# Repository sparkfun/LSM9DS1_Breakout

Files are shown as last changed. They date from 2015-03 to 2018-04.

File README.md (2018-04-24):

SparkFun LSM9DS1 Breakout
========================================

LSM9DS1 Breakout

[*LSM9DS1 Breakout (SEN-13284)*](https://www.sparkfun.com/products/13284)

The LSM9DS1 is a versatile, motion-sensing system-in-a-chip. It houses a 3-axis accelerometer, 3-axis gyroscope, and 3-axis magnetometer – nine degrees of freedom (9DOF) in a single IC! The LSM9DS1 is equipped with a digital interface, but even that is flexible: it supports both I2C and SPI, so you’ll be hard-pressed to find a microcontroller it doesn’t work with. This IMU-in-a-chip is so cool we put it on the quarter-sized breakout board you are currently viewing!

Repository Contents
-------------------

* **/Documentation** - Data sheets, additional product information
* **/Hardware** - Eagle design files (.brd, .sch)
* **/Libraries** - Libraries for use with the LSM9DS1 Breakout
* **/Production** - Production panel files (.brd)

Documentation
--------------
* **[Library](https://github.com/sparkfun/SparkFun_LSM9DS1_Arduino_Library)** - Arduino library for the LSM9DS1 Breakout.
* **[Hookup Guide](https://learn.sparkfun.com/tutorials/lsm9ds1-breakout-hookup-guide)** - Basic hookup guide for the LSM9DS1 Breakout.
* **[SparkFun Fritzing repo](https://github.com/sparkfun/Fritzing_Parts)** - Fritzing diagrams for SparkFun products. This part can be found in the products folder.

Product Versions
----------------
* [SEN-13284](https://www.sparkfun.com/products/13284)- LSM9DS1 Breakout board

Version History
---------------
* [V_1.0.0](https://github.com/sparkfun/LSM9DS1_Breakout/releases/tag/V_1.0.0) - Initial product release repository

License Information
-------------------

This product is _**open source**_! 

Please review the LICENSE.md file for license information. 

If you have any questions or concerns on licensing, please contact techsupport@sparkfun.com.

Distributed as-is; no warranty is given.

- Your friends at SparkFun.

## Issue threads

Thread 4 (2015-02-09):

Text smaller than 0.032"

ericorosel, 2015-02-09:
Not sure what GP will do, but the "2" in the "I2C" label for SJ3 is 0.025" size font

ToniCorinne, 2016-03-07:
This has been fixed. Closing this issue out.

Closed 2016-03-07.

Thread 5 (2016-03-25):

'printAttitude' was not declared in this scope

olafurjt13, 2016-03-25:
I'm trying to use the SPI example to get data from the LSM9DS1 breakout board but I can't find the printAttitude function anywhere. I've looked into the source files and can't seem to find it. Am I doing something wrong?

balamsoto, 2016-03-30:
Have same problem

bboyho, 2018-04-24:
Hi,

I was looking through the issues and noticed that you had an issue compiling. I'm not sure what Arduino IDE version you are using. However, there should be a `printAttitude()` function defined in the **LSM9DS1_Basic_SPI.ino** [ [https://github.com/sparkfun/LSM9DS1_Breakout/blob/master/Libraries/Arduino/examples/LSM9DS1_Basic_SPI/LSM9DS1_Basic_SPI.ino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](https://github.com/sparkfun/LSM9DS1_Breakout/blob/master/Libraries/Arduino/examples/LSM9DS1_Basic_SPI/LSM9DS1_Basic_SPI.ino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) ] example. Testing out with Arduino IDE v1.8.3 using the library in this repository, I had no issues compiling. I also tried testing it with the GitHub repository for the [SparkFun_LSM9DS1_Arduino_Library](https://github.com/sparkfun/SparkFun_LSM9DS1_Arduino_Library) and there were no issues.

Try using a different Arduino IDE version or reinstalling the library. Certain versions of the Arduino IDE compile differently and it may be expecting the modular functions before the `void setup(){}` and `void loop(){}` functions.

bboyho, 2018-04-24:
I just downloaded Arduino IDE v1.6.8 and confirmed that this issue was due to the Arduino IDE version. I recommend that you use a different IDE version to compile like v1.8.5.

Closed 2018-04-24.

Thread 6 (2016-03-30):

'printAttitude' was not declared in this scope

balamsoto, 2016-03-30:
Arduino 1.6.8
Mac Os el Capitan

bboyho, 2018-04-24:
It looks like you have the same issue as this case => https://github.com/sparkfun/LSM9DS1_Breakout/issues/5 . Here is my response from the other thread that may be of some use:

---

Hi,

I was looking through the issues and noticed that you had an issue compiling. I'm not sure what Arduino IDE version you are using. However, there should be a `printAttitude()` function defined in the **LSM9DS1_Basic_SPI.ino** [ [https://github.com/sparkfun/LSM9DS1_Breakout/blob/master/Libraries/Arduino/examples/LSM9DS1_Basic_SPI/LSM9DS1_Basic_SPI.ino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](https://github.com/sparkfun/LSM9DS1_Breakout/blob/master/Libraries/Arduino/examples/LSM9DS1_Basic_SPI/LSM9DS1_Basic_SPI.ino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) ] example. Testing out with Arduino IDE v1.8.3 using the library in this repository, I had no issues compiling. I also tried testing it with the GitHub repository for the [SparkFun_LSM9DS1_Arduino_Library](https://github.com/sparkfun/SparkFun_LSM9DS1_Arduino_Library) and there were no issues.

Try using a different Arduino IDE version or reinstalling the library. Certain versions of the Arduino IDE compile differently and it may be expecting the modular functions before the `void setup(){}` and `void loop(){}` functions.

bboyho, 2018-04-24:
I just downloaded Arduino IDE v1.6.8 and confirmed that this issue was due to the Arduino IDE version. I recommend that you use a different IDE version to compile like v1.8.5.

Closed 2018-04-24.

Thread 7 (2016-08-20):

No need to wait for data after Wire.requestFrom()

Koepel, 2016-08-20:
In two places in SparkFunLSM9DS1.cpp, there is a while-loop with a delay after the Wire.requestFrom() call. That while-loop is not needed and that delay is not needed.

When the Wire.requestFrom() function returns, the I2C transaction has completely finished and the received data is in the receive buffer in the Wire library. The Wire.read() only reads data from that buffer.

Grahldg, 2018-08-24:
Thanks for pointing this out, they've been removed in the latest commit.

Closed 2018-08-24.

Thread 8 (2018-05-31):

Heading is incorrect

runchangkang, 2018-05-31:
Hello I tried to implement your example basic I2C sample.
The pitch and roll are working fine.
However. the heading data is not changing correctly while rotating the board.
I tried to call calibrateMag() in setup, but the result is still incorrect
Is there any hint I can fix it? Thank you very much

Grahldg, 2018-08-27:
On further inspection I found that the way the heading was calculated was producing a range greater than 360 degrees.  I have updated the calculation and tested that it does produce values ranging from -180 degrees to 180 degrees.  All examples reflect this in the latest commit.  If you have any questions or are still experiencing any issues, please let me know.

Closed 2018-09-28.

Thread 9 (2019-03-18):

Usage of Wire library

Koepel, 2019-03-18:
The fix for [No need to wait for data after Wire.requestFrom()](https://github.com/sparkfun/LSM9DS1_Breakout/issues/7) was not fully successful.

In the file "https://github.com/sparkfun/LSM9DS1_Breakout/blob/master/Libraries/Arduino/src/SparkFunLSM9DS1.cpp"  there are two leftovers with the variable `timeout` in the functions I2CreadByte() and I2CreadBytes().
Those functions also use `Wire.endTransmission(true);` with the comment that a repeated start will be used. That is the other way around, because that parameter should be `false` for a repeated start.

The `timeout` variable can be removed. If you want, you can add a check if data was read from the sensor.

For example:
```
Wire.requestFrom(address, (uint8_t) 1);  // Read one byte from slave register address
if(Wire.available() != 1)
  return 255; //! Bad! 255 will be misinterpreted as a good value.

```
and:
```
Wire.requestFrom(address, count);  // Read bytes from slave register address
if(Wire.available() != count)
  return -1;

```

edspark, 2023-11-01:
Looks like this was silently fixed at some point years ago: https://github.com/sparkfun/LSM9DS1_Breakout/commit/ed83945ff5228455028c26a990edbc3c8d113508

Closed 2023-11-01.

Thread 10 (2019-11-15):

Example Code for I2C not working on SAMD21 Mini Breakout

savejeff, 2019-11-15:
Hi,

I had issues with the I2C Basic Example that were easily fixed:

The first try to init the imu with the line "if(!imu.begin()) fails on the first try and causes it to stuck in "while 1;"

The fix is ether to create a "while(!imu.begin()){ [print error msg and wait 1s] }"
or just wait for example 100ms before trying to connect.
This is the code fix I am proposing:

`

// The above lines will only take effect AFTER calling
  // imu.begin(), which verifies communication with the IMU
  // and turns it on.
  delay(100);
  while(!imu.begin())
  {
    Serial.println("Failed to communicate with LSM9DS1.");
    Serial.println("Double-check wiring.");
    Serial.println("Default settings in this sketch will " \
                  "work for an out of the box LSM9DS1 " \
                  "Breakout, but may need to be modified " \
                  "if the board jumpers are.");
                delay(1000);
  }

`

I also recommend adding a wait for Serial to connect to see the first error msg:

`
SerialUSB.begin(115200);
  while (!SerialUSB);
`

savan8192, 2020-01-16:
Hi Jeff, this is unlikely to make much difference!

savejeff, 2020-01-16:
It **did** make the difference

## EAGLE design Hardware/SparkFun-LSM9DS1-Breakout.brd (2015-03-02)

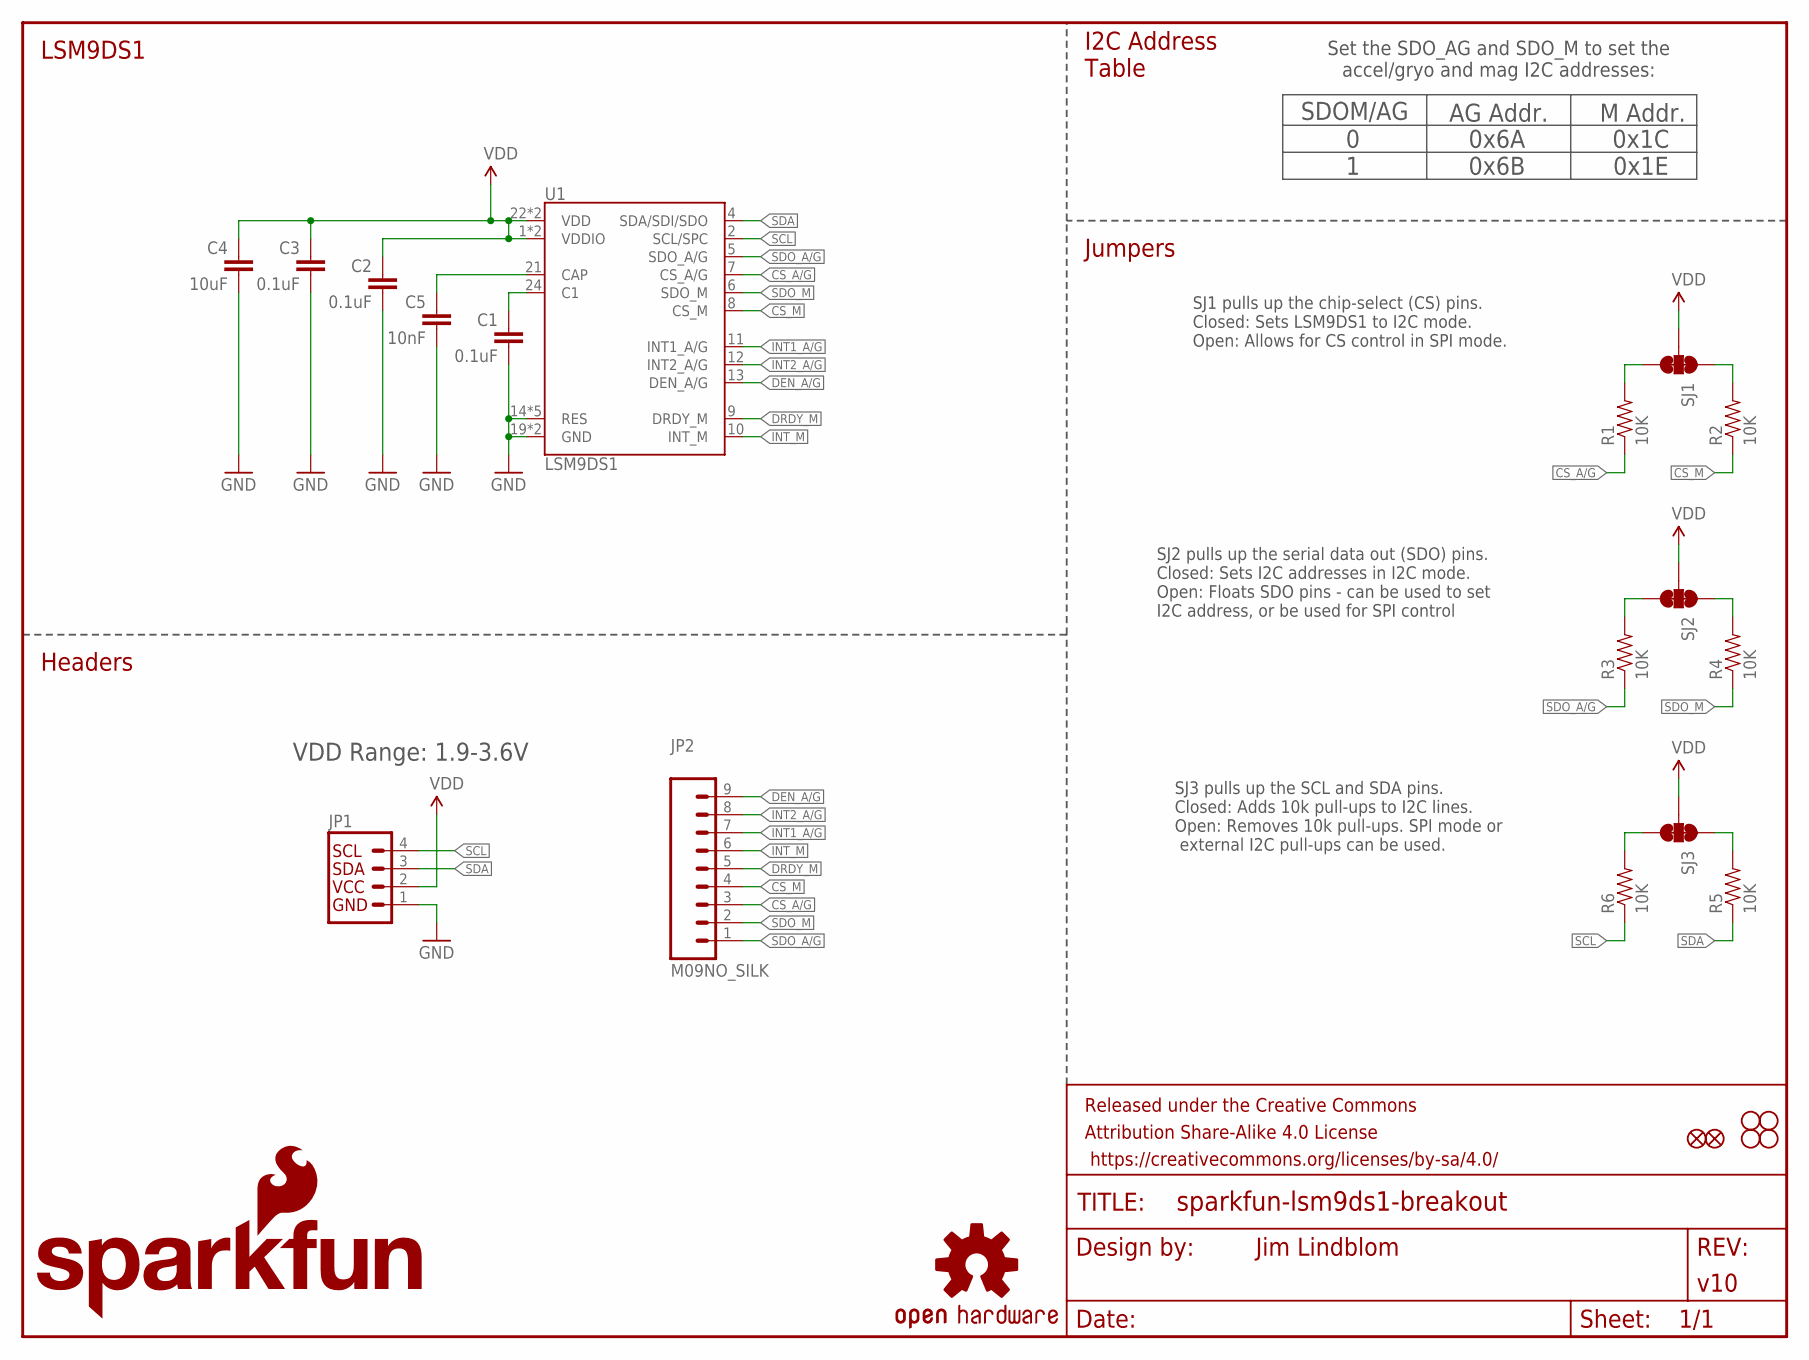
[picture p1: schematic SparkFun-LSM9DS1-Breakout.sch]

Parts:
C1, C2, C3: 0.1uF; 0603-CAP
C4: 10uF; 0603-CAP
C5: 10nF; 0603-CAP
FID1, FID2: FIDUCIAL1X2; FIDUCIAL-1X2
FRAME1: FRAME-LETTER; CREATIVE_COMMONS
JP1: I2C_STANDARD_NO_SILK; 1X04_NO_SILK
JP2: M09NO_SILK; 1X09_NO_SILK
LOGO1: SFE_LOGO_NAME.1_INCH; SFE_LOGO_NAME_.1
LOGO2: SFE_LOGO_FLAME.2_INCH; SFE_LOGO_FLAME_.2
LOGO3: OSHW-LOGOS; OSHW-LOGO-S
R1, R2, R3, R4, R5, R6: 10K; 0603-RES
SJ1, SJ2, SJ3: JUMPER-PAD-3-NC_BY_TRACE; PAD-JUMPER-3-3OF3_NC_BY_TRACE_YES_SILK_FULL_BOX
STANDOFF1, STANDOFF2, STANDOFF3, STANDOFF4: STAND-OFF
U1: LSM9DS1; LGA24-8X4

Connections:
C1: C1.1, U1.24 (C1)
CAP: C5.1, U1.21 (CAP)
CS_A/G: JP2.3, R1.1, U1.7 (CS_A/G)
CS_A/G_PU: R1.2, SJ1.3
CS_M: JP2.4, R2.1, U1.8 (CS_M)
CS_M_PU: R2.2, SJ1.1
DEN_A/G: JP2.9, U1.13 (DEN_A/G)
DRDY_M: JP2.5, U1.9 (DRDY_M)
GND: C1.2, C2.2, C3.2, C4.2, C5.2, JP1.1, U1.14 (RES), U1.15 (RES), U1.16 (RES), U1.17 (RES), U1.18 (RES), U1.19 (GND), U1.20 (GND)
INT1_A/G: JP2.7, U1.11 (INT1_A/G)
INT2_A/G: JP2.8, U1.12 (INT2_A/G)
INT_M: JP2.6, U1.10 (INT_M)
SCL: JP1.4, R6.1, U1.2 (SCL/SPC)
SCL_PU: R6.2, SJ3.3
SDA: JP1.3, R5.1, U1.4 (SDA/SDI/SDO)
SDA_PU: R5.2, SJ3.1
SDO_A/G: JP2.1, R3.1, U1.5 (SDO_A/G)
SDO_A/G_PU: R3.2, SJ2.3
SDO_M: JP2.2, R4.1, U1.6 (SDO_M)
SDO_M_PU: R4.2, SJ2.1
VDD: C2.1, C3.1, C4.1, JP1.2, SJ1.2, SJ2.2, SJ3.2, U1.1 (VDDIO), U1.3 (VDDIO), U1.22 (VDD), U1.23 (VDD)

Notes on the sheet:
SDOM/AG
0x1C 0x1E
AG Addr.
0 1
M Addr.
0x6A 0x6B
Set the SDO_AG and SDO_M to set the accel/gryo and mag I2C addresses:
SJ1 pulls up the chip-select (CS) pins. Closed: Sets LSM9DS1 to I2C mode. Open: Allows for CS control in SPI mode.
SJ2 pulls up the serial data out (SDO) pins. Closed: Sets I2C addresses in I2C mode. Open: Floats SDO pins - can be used to set I2C address, or be used for SPI control
SJ3 pulls up the SCL and SDA pins. Closed: Adds 10k pull-ups to I2C lines. Open: Removes 10k pull-ups. SPI mode or external I2C pull-ups can be used.
Jumpers
I2C Address Table
LSM9DS1
Headers
VDD Range: 1.9-3.6V

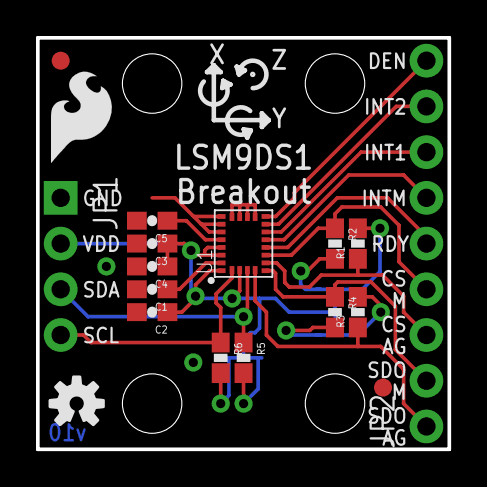
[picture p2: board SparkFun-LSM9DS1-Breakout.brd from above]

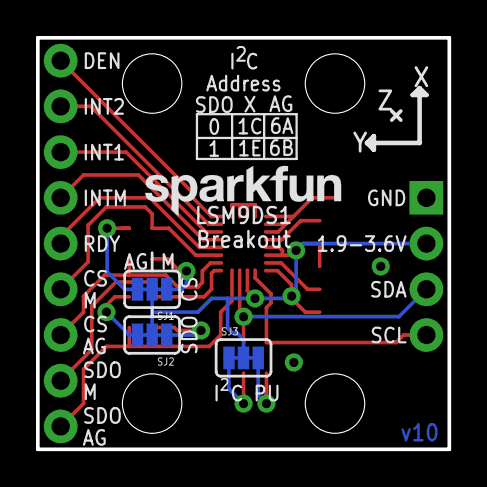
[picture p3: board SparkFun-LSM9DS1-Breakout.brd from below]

Board: 2 copper layers, 22.9 x 22.9 mm, 27 parts (4 on the bottom side), 21 nets.

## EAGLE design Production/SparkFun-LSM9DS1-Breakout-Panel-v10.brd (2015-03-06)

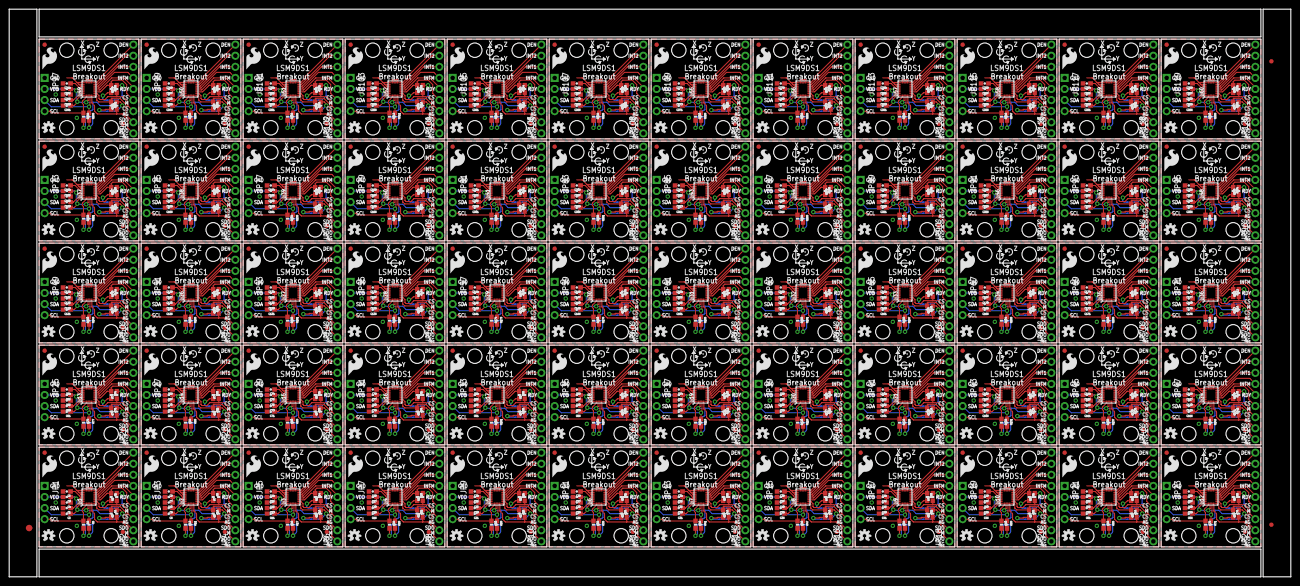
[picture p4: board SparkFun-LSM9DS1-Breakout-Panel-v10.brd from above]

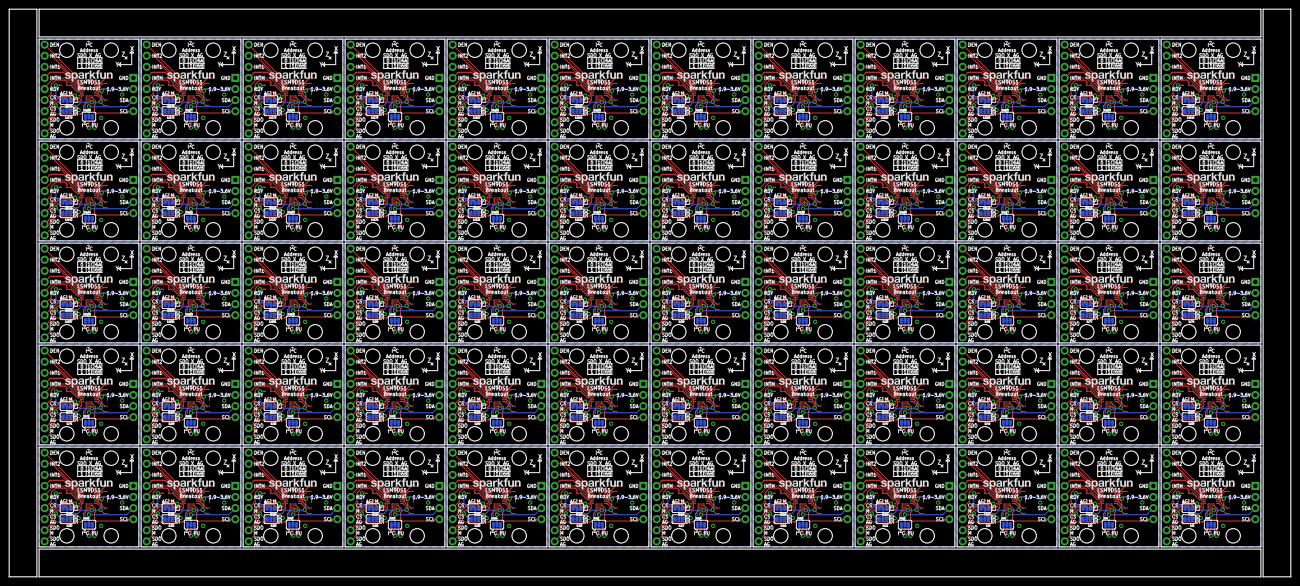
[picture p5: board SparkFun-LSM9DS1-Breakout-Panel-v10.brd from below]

Board: 2 copper layers, 293.6 x 130.0 mm, 1563 parts (240 on the bottom side), 1260 nets.

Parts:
C1, C2, C3, C6, C7, C8, C11, C12, C13, C16, C17, C18, C21, C22, C23, C26, C27, C28, C31, C32, C33, C36, C37, C38, C41, C42, C43, C46, C47, C48, C51, C52, C53, C56, C57, C58, C61, C62, C63, C66, C67, C68, C71, C72, C73, C76, C77, C78, C81, C82, C83, C86, C87, C88, C91, C92, C93, C96, C97, C98, C101, C102, C103, C106, C107, C108, C111, C112, C113, C116, C117, C118, C121, C122, C123, C126, C127, C128, C131, C132, C133, C136, C137, C138, C141, C142, C143, C146, C147, C148, C151, C152, C153, C156, C157, C158, C161, C162, C163, C166, C167, C168, C171, C172, C173, C176, C177, C178, C181, C182, C183, C186, C187, C188, C191, C192, C193, C196, C197, C198, C201, C202, C203, C206, C207, C208, C211, C212, C213, C216, C217, C218, C221, C222, C223, C226, C227, C228, C231, C232, C233, C236, C237, C238, C241, C242, C243, C246, C247, C248, C251, C252, C253, C256, C257, C258, C261, C262, C263, C266, C267, C268, C271, C272, C273, C276, C277, C278, C281, C282, C283, C286, C287, C288, C291, C292, C293, C296, C297, C298: 0.1uF; 0603-CAP
C4, C10, C15, C20, C25, C30, C35, C40, C45, C50, C55, C60, C65, C70, C75, C80, C85, C90, C95, C100, C105, C110, C115, C120, C125, C130, C135, C140, C145, C150, C155, C160, C165, C170, C175, C180, C185, C190, C195, C200, C205, C210, C215, C220, C225, C230, C235, C240, C245, C250, C255, C260, C265, C270, C275, C280, C285, C290, C295, C300: 10uF; 0603-CAP
C5, C9, C14, C19, C24, C29, C34, C39, C44, C49, C54, C59, C64, C69, C74, C79, C84, C89, C94, C99, C104, C109, C114, C119, C124, C129, C134, C139, C144, C149, C154, C159, C164, C169, C174, C179, C184, C189, C194, C199, C204, C209, C214, C219, C224, C229, C234, C239, C244, C249, C254, C259, C264, C269, C274, C279, C284, C289, C294, C299: 10nF; 0603-CAP
E$1: FIDUCIAL-1.5X3
E$4, E$5: FIDUCIAL-1X2
FID1, FID2, FID3, FID4, FID5, FID6, FID7, FID8, FID9, FID10, FID11, FID12, FID13, FID14, FID15, FID16, FID17, FID18, FID19, FID20, FID21, FID22, FID23, FID24, FID25, FID26, FID27, FID28, FID29, FID30, FID31, FID32, FID33, FID34, FID35, FID36, FID37, FID38, FID39, FID40, FID41, FID42, FID43, FID44, FID45, FID46, FID47, FID48, FID49, FID50, FID51, FID52, FID53, FID54, FID55, FID56, FID57, FID58, FID59, FID60, FID61, FID62, FID63, FID64, FID65, FID66, FID67, FID68, FID69, FID70, FID71, FID72, FID73, FID74, FID75, FID76, FID77, FID78, FID79, FID80, FID81, FID82, FID83, FID84, FID85, FID86, FID87, FID88, FID89, FID90, FID91, FID92, FID93, FID94, FID95, FID96, FID97, FID98, FID99, FID100, FID101, FID102, FID103, FID104, FID105, FID106, FID107, FID108, FID109, FID110, FID111, FID112, FID113, FID114, FID115, FID116, FID117, FID118, FID119, FID120: FIDUCIAL1X2; FIDUCIAL-1X2
JP1, JP3, JP5, JP7, JP9, JP11, JP13, JP15, JP17, JP19, JP21, JP23, JP25, JP27, JP29, JP31, JP33, JP35, JP37, JP39, JP41, JP43, JP45, JP47, JP49, JP51, JP53, JP55, JP57, JP59, JP61, JP63, JP65, JP67, JP69, JP71, JP73, JP75, JP77, JP79, JP81, JP83, JP85, JP87, JP89, JP91, JP93, JP95, JP97, JP99, JP101, JP103, JP105, JP107, JP109, JP111, JP113, JP115, JP117, JP119: 1X04_NO_SILK
JP2, JP4, JP6, JP8, JP10, JP12, JP14, JP16, JP18, JP20, JP22, JP24, JP26, JP28, JP30, JP32, JP34, JP36, JP38, JP40, JP42, JP44, JP46, JP48, JP50, JP52, JP54, JP56, JP58, JP60, JP62, JP64, JP66, JP68, JP70, JP72, JP74, JP76, JP78, JP80, JP82, JP84, JP86, JP88, JP90, JP92, JP94, JP96, JP98, JP100, JP102, JP104, JP106, JP108, JP110, JP112, JP114, JP116, JP118, JP120: M09NO_SILK; 1X09_NO_SILK
LOGO1, LOGO4, LOGO7, LOGO10, LOGO13, LOGO16, LOGO19, LOGO22, LOGO25, LOGO28, LOGO31, LOGO34, LOGO37, LOGO40, LOGO43, LOGO46, LOGO49, LOGO52, LOGO55, LOGO58, LOGO61, LOGO64, LOGO67, LOGO70, LOGO73, LOGO76, LOGO79, LOGO82, LOGO85, LOGO88, LOGO91, LOGO94, LOGO97, LOGO100, LOGO103, LOGO106, LOGO109, LOGO112, LOGO115, LOGO118, LOGO121, LOGO124, LOGO127, LOGO130, LOGO133, LOGO136, LOGO139, LOGO142, LOGO145, LOGO148, LOGO151, LOGO154, LOGO157, LOGO160, LOGO163, LOGO166, LOGO169, LOGO172, LOGO175, LOGO178: SFE_LOGO_NAME.1_INCH; SFE_LOGO_NAME_.1
LOGO2, LOGO5, LOGO8, LOGO11, LOGO14, LOGO17, LOGO20, LOGO23, LOGO26, LOGO29, LOGO32, LOGO35, LOGO38, LOGO41, LOGO44, LOGO47, LOGO50, LOGO53, LOGO56, LOGO59, LOGO62, LOGO65, LOGO68, LOGO71, LOGO74, LOGO77, LOGO80, LOGO83, LOGO86, LOGO89, LOGO92, LOGO95, LOGO98, LOGO101, LOGO104, LOGO107, LOGO110, LOGO113, LOGO116, LOGO119, LOGO122, LOGO125, LOGO128, LOGO131, LOGO134, LOGO137, LOGO140, LOGO143, LOGO146, LOGO149, LOGO152, LOGO155, LOGO158, LOGO161, LOGO164, LOGO167, LOGO170, LOGO173, LOGO176, LOGO179: SFE_LOGO_FLAME.2_INCH; SFE_LOGO_FLAME_.2
LOGO3, LOGO6, LOGO9, LOGO12, LOGO15, LOGO18, LOGO21, LOGO24, LOGO27, LOGO30, LOGO33, LOGO36, LOGO39, LOGO42, LOGO45, LOGO48, LOGO51, LOGO54, LOGO57, LOGO60, LOGO63, LOGO66, LOGO69, LOGO72, LOGO75, LOGO78, LOGO81, LOGO84, LOGO87, LOGO90, LOGO93, LOGO96, LOGO99, LOGO102, LOGO105, LOGO108, LOGO111, LOGO114, LOGO117, LOGO120, LOGO123, LOGO126, LOGO129, LOGO132, LOGO135, LOGO138, LOGO141, LOGO144, LOGO147, LOGO150, LOGO153, LOGO156, LOGO159, LOGO162, LOGO165, LOGO168, LOGO171, LOGO174, LOGO177, LOGO180: OSHW-LOGOS; OSHW-LOGO-S
R1, R2, R3, R4, R5, R6, R7, R8, R9, R10, R11, R12, R13, R14, R15, R16, R17, R18, R19, R20, R21, R22, R23, R24, R25, R26, R27, R28, R29, R30, R31, R32, R33, R34, R35, R36, R37, R38, R39, R40, R41, R42, R43, R44, R45, R46, R47, R48, R49, R50, R51, R52, R53, R54, R55, R56, R57, R58, R59, R60, R61, R62, R63, R64, R65, R66, R67, R68, R69, R70, R71, R72, R73, R74, R75, R76, R77, R78, R79, R80, R81, R82, R83, R84, R85, R86, R87, R88, R89, R90, R91, R92, R93, R94, R95, R96, R97, R98, R99, R100, R101, R102, R103, R104, R105, R106, R107, R108, R109, R110, R111, R112, R113, R114, R115, R116, R117, R118, R119, R120, R121, R122, R123, R124, R125, R126, R127, R128, R129, R130, R131, R132, R133, R134, R135, R136, R137, R138, R139, R140, R141, R142, R143, R144, R145, R146, R147, R148, R149, R150, R151, R152, R153, R154, R155, R156, R157, R158, R159, R160, R161, R162, R163, R164, R165, R166, R167, R168, R169, R170, R171, R172, R173, R174, R175, R176, R177, R178, R179, R180, R181, R182, R183, R184, R185, R186, R187, R188, R189, R190, R191, R192, R193, R194, R195, R196, R197, R198, R199, R200, R201, R202, R203, R204, R205, R206, R207, R208, R209, R210, R211, R212, R213, R214, R215, R216, R217, R218, R219, R220, R221, R222, R223, R224, R225, R226, R227, R228, R229, R230, R231, R232, R233, R234, R235, R236, R237, R238, R239, R240, R241, R242, R243, R244, R245, R246, R247, R248, R249, R250, R251, R252, R253, R254, R255, R256, R257, R258, R259, R260, R261, R262, R263, R264, R265, R266, R267, R268, R269, R270, R271, R272, R273, R274, R275, R276, R277, R278, R279, R280, R281, R282, R283, R284, R285, R286, R287, R288, R289, R290, R291, R292, R293, R294, R295, R296, R297, R298, R299, R300, R301, R302, R303, R304, R305, R306, R307, R308, R309, R310, R311, R312, R313, R314, R315, R316, R317, R318, R319, R320, R321, R322, R323, R324, R325, R326, R327, R328, R329, R330, R331, R332, R333, R334, R335, R336, R337, R338, R339, R340, R341, R342, R343, R344, R345, R346, R347, R348, R349, R350, R351, R352, R353, R354, R355, R356, R357, R358, R359, R360: 10K; 0603-RES
SJ1, SJ2, SJ3, SJ4, SJ5, SJ6, SJ7, SJ8, SJ9, SJ10, SJ11, SJ12, SJ13, SJ14, SJ15, SJ16, SJ17, SJ18, SJ19, SJ20, SJ21, SJ22, SJ23, SJ24, SJ25, SJ26, SJ27, SJ28, SJ29, SJ30, SJ31, SJ32, SJ33, SJ34, SJ35, SJ36, SJ37, SJ38, SJ39, SJ40, SJ41, SJ42, SJ43, SJ44, SJ45, SJ46, SJ47, SJ48, SJ49, SJ50, SJ51, SJ52, SJ53, SJ54, SJ55, SJ56, SJ57, SJ58, SJ59, SJ60, SJ61, SJ62, SJ63, SJ64, SJ65, SJ66, SJ67, SJ68, SJ69, SJ70, SJ71, SJ72, SJ73, SJ74, SJ75, SJ76, SJ77, SJ78, SJ79, SJ80, SJ81, SJ82, SJ83, SJ84, SJ85, SJ86, SJ87, SJ88, SJ89, SJ90, SJ91, SJ92, SJ93, SJ94, SJ95, SJ96, SJ97, SJ98, SJ99, SJ100, SJ101, SJ102, SJ103, SJ104, SJ105, SJ106, SJ107, SJ108, SJ109, SJ110, SJ111, SJ112, SJ113, SJ114, SJ115, SJ116, SJ117, SJ118, SJ119, SJ120, SJ121, SJ122, SJ123, SJ124, SJ125, SJ126, SJ127, SJ128, SJ129, SJ130, SJ131, SJ132, SJ133, SJ134, SJ135, SJ136, SJ137, SJ138, SJ139, SJ140, SJ141, SJ142, SJ143, SJ144, SJ145, SJ146, SJ147, SJ148, SJ149, SJ150, SJ151, SJ152, SJ153, SJ154, SJ155, SJ156, SJ157, SJ158, SJ159, SJ160, SJ161, SJ162, SJ163, SJ164, SJ165, SJ166, SJ167, SJ168, SJ169, SJ170, SJ171, SJ172, SJ173, SJ174, SJ175, SJ176, SJ177, SJ178, SJ179, SJ180: PAD-JUMPER-3-3OF3_NC_BY_TRACE_YES_SILK_FULL_BOX
STANDOFF1, STANDOFF2, STANDOFF3, STANDOFF4, STANDOFF5, STANDOFF6, STANDOFF7, STANDOFF8, STANDOFF9, STANDOFF10, STANDOFF11, STANDOFF12, STANDOFF13, STANDOFF14, STANDOFF15, STANDOFF16, STANDOFF17, STANDOFF18, STANDOFF19, STANDOFF20, STANDOFF21, STANDOFF22, STANDOFF23, STANDOFF24, STANDOFF25, STANDOFF26, STANDOFF27, STANDOFF28, STANDOFF29, STANDOFF30, STANDOFF31, STANDOFF32, STANDOFF33, STANDOFF34, STANDOFF35, STANDOFF36, STANDOFF37, STANDOFF38, STANDOFF39, STANDOFF40, STANDOFF41, STANDOFF42, STANDOFF43, STANDOFF44, STANDOFF45, STANDOFF46, STANDOFF47, STANDOFF48, STANDOFF49, STANDOFF50, STANDOFF51, STANDOFF52, STANDOFF53, STANDOFF54, STANDOFF55, STANDOFF56, STANDOFF57, STANDOFF58, STANDOFF59, STANDOFF60, STANDOFF61, STANDOFF62, STANDOFF63, STANDOFF64, STANDOFF65, STANDOFF66, STANDOFF67, STANDOFF68, STANDOFF69, STANDOFF70, STANDOFF71, STANDOFF72, STANDOFF73, STANDOFF74, STANDOFF75, STANDOFF76, STANDOFF77, STANDOFF78, STANDOFF79, STANDOFF80, STANDOFF81, STANDOFF82, STANDOFF83, STANDOFF84, STANDOFF85, STANDOFF86, STANDOFF87, STANDOFF88, STANDOFF89, STANDOFF90, STANDOFF91, STANDOFF92, STANDOFF93, STANDOFF94, STANDOFF95, STANDOFF96, STANDOFF97, STANDOFF98, STANDOFF99, STANDOFF100, STANDOFF101, STANDOFF102, STANDOFF103, STANDOFF104, STANDOFF105, STANDOFF106, STANDOFF107, STANDOFF108, STANDOFF109, STANDOFF110, STANDOFF111, STANDOFF112, STANDOFF113, STANDOFF114, STANDOFF115, STANDOFF116, STANDOFF117, STANDOFF118, STANDOFF119, STANDOFF120, STANDOFF121, STANDOFF122, STANDOFF123, STANDOFF124, STANDOFF125, STANDOFF126, STANDOFF127, STANDOFF128, STANDOFF129, STANDOFF130, STANDOFF131, STANDOFF132, STANDOFF133, STANDOFF134, STANDOFF135, STANDOFF136, STANDOFF137, STANDOFF138, STANDOFF139, STANDOFF140, STANDOFF141, STANDOFF142, STANDOFF143, STANDOFF144, STANDOFF145, STANDOFF146, STANDOFF147, STANDOFF148, STANDOFF149, STANDOFF150, STANDOFF151, STANDOFF152, STANDOFF153, STANDOFF154, STANDOFF155, STANDOFF156, STANDOFF157, STANDOFF158, STANDOFF159, STANDOFF160, STANDOFF161, STANDOFF162, STANDOFF163, STANDOFF164, STANDOFF165, STANDOFF166, STANDOFF167, STANDOFF168, STANDOFF169, STANDOFF170, STANDOFF171, STANDOFF172, STANDOFF173, STANDOFF174, STANDOFF175, STANDOFF176, STANDOFF177, STANDOFF178, STANDOFF179, STANDOFF180, STANDOFF181, STANDOFF182, STANDOFF183, STANDOFF184, STANDOFF185, STANDOFF186, STANDOFF187, STANDOFF188, STANDOFF189, STANDOFF190, STANDOFF191, STANDOFF192, STANDOFF193, STANDOFF194, STANDOFF195, STANDOFF196, STANDOFF197, STANDOFF198, STANDOFF199, STANDOFF200, STANDOFF201, STANDOFF202, STANDOFF203, STANDOFF204, STANDOFF205, STANDOFF206, STANDOFF207, STANDOFF208, STANDOFF209, STANDOFF210, STANDOFF211, STANDOFF212, STANDOFF213, STANDOFF214, STANDOFF215, STANDOFF216, STANDOFF217, STANDOFF218, STANDOFF219, STANDOFF220, STANDOFF221, STANDOFF222, STANDOFF223, STANDOFF224, STANDOFF225, STANDOFF226, STANDOFF227, STANDOFF228, STANDOFF229, STANDOFF230, STANDOFF231, STANDOFF232, STANDOFF233, STANDOFF234, STANDOFF235, STANDOFF236, STANDOFF237, STANDOFF238, STANDOFF239, STANDOFF240: STAND-OFF
U1, U2, U3, U4, U5, U6, U7, U8, U9, U10, U11, U12, U13, U14, U15, U16, U17, U18, U19, U20, U21, U22, U23, U24, U25, U26, U27, U28, U29, U30, U31, U32, U33, U34, U35, U36, U37, U38, U39, U40, U41, U42, U43, U44, U45, U46, U47, U48, U49, U50, U51, U52, U53, U54, U55, U56, U57, U58, U59, U60: LSM9DS1; LGA24-8X4

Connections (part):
C1: C1.1, U1.24
C2: C8.1, U2.24
C3: C13.1, U3.24
C4: C18.1, U4.24
C5: C23.1, U5.24
C6: C28.1, U6.24
C7: C33.1, U7.24
C8: C38.1, U8.24
C9: C43.1, U9.24
C10: C48.1, U10.24
C11: C53.1, U11.24
C12: C58.1, U12.24
C13: C63.1, U13.24
C14: C68.1, U14.24
C15: C73.1, U15.24
C16: C78.1, U16.24
C17: C83.1, U17.24
C18: C88.1, U18.24
C19: C93.1, U19.24
C20: C98.1, U20.24
C21: C103.1, U21.24
C22: C108.1, U22.24
C23: C113.1, U23.24
C24: C118.1, U24.24
C25: C123.1, U25.24
C26: C128.1, U26.24
C27: C133.1, U27.24
C28: C138.1, U28.24
C29: C143.1, U29.24
C30: C148.1, U30.24
C31: C153.1, U31.24
C32: C158.1, U32.24
C33: C163.1, U33.24
C34: C168.1, U34.24
C35: C173.1, U35.24
C36: C178.1, U36.24
C37: C183.1, U37.24
C38: C188.1, U38.24
C39: C193.1, U39.24
C40: C198.1, U40.24
C41: C203.1, U41.24
C42: C208.1, U42.24
C43: C213.1, U43.24
C44: C218.1, U44.24
C45: C223.1, U45.24
C46: C228.1, U46.24
C47: C233.1, U47.24
C48: C238.1, U48.24
C49: C243.1, U49.24
C50: C248.1, U50.24
C51: C253.1, U51.24
C52: C258.1, U52.24
C53: C263.1, U53.24
C54: C268.1, U54.24
C55: C273.1, U55.24
C56: C278.1, U56.24
C57: C283.1, U57.24
C58: C288.1, U58.24
C59: C293.1, U59.24
C60: C298.1, U60.24
CAP: C5.1, U1.21
CAP1: C9.1, U2.21
CAP2: C14.1, U3.21
CAP3: C19.1, U4.21
CAP4: C24.1, U5.21
CAP5: C29.1, U6.21
CAP6: C34.1, U7.21
CAP7: C39.1, U8.21
CAP8: C44.1, U9.21
CAP9: C49.1, U10.21
CAP10: C54.1, U11.21
CAP11: C59.1, U12.21
CAP12: C64.1, U13.21
CAP13: C69.1, U14.21
CAP14: C74.1, U15.21
CAP15: C79.1, U16.21
CAP16: C84.1, U17.21
CAP17: C89.1, U18.21
CAP18: C94.1, U19.21
CAP19: C99.1, U20.21
CAP20: C104.1, U21.21
CAP21: C109.1, U22.21
CAP22: C114.1, U23.21
CAP23: C119.1, U24.21
CAP24: C124.1, U25.21
CAP25: C129.1, U26.21
CAP26: C134.1, U27.21
CAP27: C139.1, U28.21
CAP28: C144.1, U29.21
CAP29: C149.1, U30.21
CAP30: C154.1, U31.21
CAP31: C159.1, U32.21
CAP32: C164.1, U33.21
CAP33: C169.1, U34.21
CAP34: C174.1, U35.21
CAP35: C179.1, U36.21
CAP36: C184.1, U37.21
CAP37: C189.1, U38.21
CAP38: C194.1, U39.21
CAP39: C199.1, U40.21
CAP40: C204.1, U41.21
CAP41: C209.1, U42.21
CAP42: C214.1, U43.21
CAP43: C219.1, U44.21
CAP44: C224.1, U45.21
CAP45: C229.1, U46.21
CAP46: C234.1, U47.21
CAP47: C239.1, U48.21
CAP48: C244.1, U49.21
CAP49: C249.1, U50.21
CAP50: C254.1, U51.21
CAP51: C259.1, U52.21
CAP52: C264.1, U53.21
CAP53: C269.1, U54.21
CAP54: C274.1, U55.21
CAP55: C279.1, U56.21
CAP56: C284.1, U57.21
CAP57: C289.1, U58.21
CAP58: C294.1, U59.21
CAP59: C299.1, U60.21
CS_A/G: JP2.3, R1.1, U1.7
CS_A/G1: JP4.3, R7.1, U2.7
CS_A/G2: JP6.3, R13.1, U3.7
CS_A/G3: JP8.3, R19.1, U4.7
CS_A/G4: JP10.3, R25.1, U5.7
CS_A/G5: JP12.3, R31.1, U6.7
CS_A/G6: JP14.3, R37.1, U7.7
CS_A/G7: JP16.3, R43.1, U8.7
CS_A/G8: JP18.3, R49.1, U9.7
CS_A/G9: JP20.3, R55.1, U10.7
CS_A/G10: JP22.3, R61.1, U11.7
CS_A/G11: JP24.3, R67.1, U12.7
CS_A/G12: JP26.3, R73.1, U13.7
CS_A/G13: JP28.3, R79.1, U14.7
CS_A/G14: JP30.3, R85.1, U15.7
CS_A/G15: JP32.3, R91.1, U16.7
CS_A/G16: JP34.3, R97.1, U17.7
CS_A/G17: JP36.3, R103.1, U18.7
CS_A/G18: JP38.3, R109.1, U19.7
CS_A/G19: JP40.3, R115.1, U20.7
CS_A/G20: JP42.3, R121.1, U21.7
CS_A/G21: JP44.3, R127.1, U22.7
CS_A/G22: JP46.3, R133.1, U23.7
CS_A/G23: JP48.3, R139.1, U24.7
CS_A/G24: JP50.3, R145.1, U25.7
CS_A/G25: JP52.3, R151.1, U26.7
CS_A/G26: JP54.3, R157.1, U27.7
CS_A/G27: JP56.3, R163.1, U28.7
CS_A/G28: JP58.3, R169.1, U29.7
CS_A/G29: JP60.3, R175.1, U30.7
CS_A/G30: JP62.3, R181.1, U31.7
CS_A/G31: JP64.3, R187.1, U32.7
CS_A/G32: JP66.3, R193.1, U33.7
CS_A/G33: JP68.3, R199.1, U34.7
CS_A/G34: JP70.3, R205.1, U35.7
CS_A/G35: JP72.3, R211.1, U36.7
CS_A/G36: JP74.3, R217.1, U37.7
CS_A/G37: JP76.3, R223.1, U38.7
CS_A/G38: JP78.3, R229.1, U39.7
CS_A/G39: JP80.3, R235.1, U40.7
CS_A/G40: JP82.3, R241.1, U41.7
CS_A/G41: JP84.3, R247.1, U42.7
CS_A/G42: JP86.3, R253.1, U43.7
CS_A/G43: JP88.3, R259.1, U44.7
CS_A/G44: JP90.3, R265.1, U45.7
CS_A/G45: JP92.3, R271.1, U46.7
CS_A/G46: JP94.3, R277.1, U47.7
CS_A/G47: JP96.3, R283.1, U48.7
CS_A/G48: JP98.3, R289.1, U49.7
CS_A/G49: JP100.3, R295.1, U50.7
CS_A/G50: JP102.3, R301.1, U51.7
CS_A/G51: JP104.3, R307.1, U52.7
CS_A/G52: JP106.3, R313.1, U53.7
CS_A/G53: JP108.3, R319.1, U54.7
CS_A/G54: JP110.3, R325.1, U55.7
CS_A/G55: JP112.3, R331.1, U56.7
CS_A/G56: JP114.3, R337.1, U57.7
CS_A/G57: JP116.3, R343.1, U58.7
CS_A/G58: JP118.3, R349.1, U59.7
CS_A/G59: JP120.3, R355.1, U60.7
CS_A/G_PU: R1.2, SJ1.3
CS_A/G_PU1: R7.2, SJ4.3
CS_A/G_PU2: R13.2, SJ7.3
CS_A/G_PU3: R19.2, SJ10.3
CS_A/G_PU4: R25.2, SJ13.3
CS_A/G_PU5: R31.2, SJ16.3
CS_A/G_PU6: R37.2, SJ19.3
CS_A/G_PU7: R43.2, SJ22.3
CS_A/G_PU8: R49.2, SJ25.3
CS_A/G_PU9: R55.2, SJ28.3
CS_A/G_PU10: R61.2, SJ31.3
CS_A/G_PU11: R67.2, SJ34.3
CS_A/G_PU12: R73.2, SJ37.3
CS_A/G_PU13: R79.2, SJ40.3
CS_A/G_PU14: R85.2, SJ43.3
CS_A/G_PU15: R91.2, SJ46.3
CS_A/G_PU16: R97.2, SJ49.3
CS_A/G_PU17: R103.2, SJ52.3
CS_A/G_PU18: R109.2, SJ55.3
CS_A/G_PU19: R115.2, SJ58.3
CS_A/G_PU20: R121.2, SJ61.3
CS_A/G_PU21: R127.2, SJ64.3
CS_A/G_PU22: R133.2, SJ67.3
CS_A/G_PU23: R139.2, SJ70.3
CS_A/G_PU24: R145.2, SJ73.3
CS_A/G_PU25: R151.2, SJ76.3
CS_A/G_PU26: R157.2, SJ79.3
CS_A/G_PU27: R163.2, SJ82.3
CS_A/G_PU28: R169.2, SJ85.3
CS_A/G_PU29: R175.2, SJ88.3
CS_A/G_PU30: R181.2, SJ91.3
CS_A/G_PU31: R187.2, SJ94.3
CS_A/G_PU32: R193.2, SJ97.3
CS_A/G_PU33: R199.2, SJ100.3
CS_A/G_PU34: R205.2, SJ103.3
CS_A/G_PU35: R211.2, SJ106.3
CS_A/G_PU36: R217.2, SJ109.3
CS_A/G_PU37: R223.2, SJ112.3
CS_A/G_PU38: R229.2, SJ115.3
CS_A/G_PU39: R235.2, SJ118.3
CS_A/G_PU40: R241.2, SJ121.3
CS_A/G_PU41: R247.2, SJ124.3
CS_A/G_PU42: R253.2, SJ127.3
CS_A/G_PU43: R259.2, SJ130.3
CS_A/G_PU44: R265.2, SJ133.3
CS_A/G_PU45: R271.2, SJ136.3
CS_A/G_PU46: R277.2, SJ139.3
CS_A/G_PU47: R283.2, SJ142.3
CS_A/G_PU48: R289.2, SJ145.3
CS_A/G_PU49: R295.2, SJ148.3
CS_A/G_PU50: R301.2, SJ151.3
CS_A/G_PU51: R307.2, SJ154.3
CS_A/G_PU52: R313.2, SJ157.3
CS_A/G_PU53: R319.2, SJ160.3
CS_A/G_PU54: R325.2, SJ163.3
CS_A/G_PU55: R331.2, SJ166.3
CS_A/G_PU56: R337.2, SJ169.3
CS_A/G_PU57: R343.2, SJ172.3
CS_A/G_PU58: R349.2, SJ175.3
CS_A/G_PU59: R355.2, SJ178.3
CS_M: JP2.4, R2.1, U1.8
CS_M1: JP4.4, R8.1, U2.8
CS_M2: JP6.4, R14.1, U3.8
CS_M3: JP8.4, R20.1, U4.8
CS_M4: JP10.4, R26.1, U5.8
CS_M5: JP12.4, R32.1, U6.8
CS_M6: JP14.4, R38.1, U7.8
CS_M7: JP16.4, R44.1, U8.8
CS_M8: JP18.4, R50.1, U9.8
CS_M9: JP20.4, R56.1, U10.8
CS_M10: JP22.4, R62.1, U11.8
CS_M11: JP24.4, R68.1, U12.8
CS_M12: JP26.4, R74.1, U13.8
CS_M13: JP28.4, R80.1, U14.8
CS_M14: JP30.4, R86.1, U15.8
CS_M15: JP32.4, R92.1, U16.8
CS_M16: JP34.4, R98.1, U17.8
CS_M17: JP36.4, R104.1, U18.8
CS_M18: JP38.4, R110.1, U19.8
CS_M19: JP40.4, R116.1, U20.8
CS_M20: JP42.4, R122.1, U21.8
CS_M21: JP44.4, R128.1, U22.8
CS_M22: JP46.4, R134.1, U23.8
CS_M23: JP48.4, R140.1, U24.8
CS_M24: JP50.4, R146.1, U25.8
CS_M25: JP52.4, R152.1, U26.8
CS_M26: JP54.4, R158.1, U27.8
CS_M27: JP56.4, R164.1, U28.8
CS_M28: JP58.4, R170.1, U29.8
CS_M29: JP60.4, R176.1, U30.8
CS_M30: JP62.4, R182.1, U31.8
CS_M31: JP64.4, R188.1, U32.8
CS_M32: JP66.4, R194.1, U33.8
CS_M33: JP68.4, R200.1, U34.8
CS_M34: JP70.4, R206.1, U35.8
CS_M35: JP72.4, R212.1, U36.8
CS_M36: JP74.4, R218.1, U37.8
CS_M37: JP76.4, R224.1, U38.8
CS_M38: JP78.4, R230.1, U39.8
CS_M39: JP80.4, R236.1, U40.8
CS_M40: JP82.4, R242.1, U41.8
CS_M41: JP84.4, R248.1, U42.8
CS_M42: JP86.4, R254.1, U43.8
CS_M43: JP88.4, R260.1, U44.8
CS_M44: JP90.4, R266.1, U45.8
CS_M45: JP92.4, R272.1, U46.8
CS_M46: JP94.4, R278.1, U47.8
CS_M47: JP96.4, R284.1, U48.8
CS_M48: JP98.4, R290.1, U49.8
CS_M49: JP100.4, R296.1, U50.8
CS_M50: JP102.4, R302.1, U51.8
CS_M51: JP104.4, R308.1, U52.8
CS_M52: JP106.4, R314.1, U53.8
CS_M53: JP108.4, R320.1, U54.8
CS_M54: JP110.4, R326.1, U55.8
CS_M55: JP112.4, R332.1, U56.8
CS_M56: JP114.4, R338.1, U57.8
CS_M57: JP116.4, R344.1, U58.8
CS_M58: JP118.4, R350.1, U59.8
CS_M59: JP120.4, R356.1, U60.8
CS_M_PU: R2.2, SJ1.1
CS_M_PU1: R8.2, SJ4.1
CS_M_PU2: R14.2, SJ7.1
CS_M_PU3: R20.2, SJ10.1
CS_M_PU4: R26.2, SJ13.1
CS_M_PU5: R32.2, SJ16.1
CS_M_PU6: R38.2, SJ19.1
CS_M_PU7: R44.2, SJ22.1
CS_M_PU8: R50.2, SJ25.1
CS_M_PU9: R56.2, SJ28.1
CS_M_PU10: R62.2, SJ31.1
CS_M_PU11: R68.2, SJ34.1
CS_M_PU12: R74.2, SJ37.1
CS_M_PU13: R80.2, SJ40.1
CS_M_PU14: R86.2, SJ43.1
CS_M_PU15: R92.2, SJ46.1
CS_M_PU16: R98.2, SJ49.1
CS_M_PU17: R104.2, SJ52.1
CS_M_PU18: R110.2, SJ55.1
CS_M_PU19: R116.2, SJ58.1
CS_M_PU20: R122.2, SJ61.1
CS_M_PU21: R128.2, SJ64.1
CS_M_PU22: R134.2, SJ67.1
CS_M_PU23: R140.2, SJ70.1
CS_M_PU24: R146.2, SJ73.1
CS_M_PU25: R152.2, SJ76.1
CS_M_PU26: R158.2, SJ79.1
CS_M_PU27: R164.2, SJ82.1
CS_M_PU28: R170.2, SJ85.1
CS_M_PU29: R176.2, SJ88.1
CS_M_PU30: R182.2, SJ91.1
CS_M_PU31: R188.2, SJ94.1
CS_M_PU32: R194.2, SJ97.1
CS_M_PU33: R200.2, SJ100.1
CS_M_PU34: R206.2, SJ103.1
CS_M_PU35: R212.2, SJ106.1
CS_M_PU36: R218.2, SJ109.1
CS_M_PU37: R224.2, SJ112.1
CS_M_PU38: R230.2, SJ115.1
CS_M_PU39: R236.2, SJ118.1
CS_M_PU40: R242.2, SJ121.1
CS_M_PU41: R248.2, SJ124.1
CS_M_PU42: R254.2, SJ127.1
CS_M_PU43: R260.2, SJ130.1
CS_M_PU44: R266.2, SJ133.1
CS_M_PU45: R272.2, SJ136.1
CS_M_PU46: R278.2, SJ139.1
CS_M_PU47: R284.2, SJ142.1
CS_M_PU48: R290.2, SJ145.1
CS_M_PU49: R296.2, SJ148.1
CS_M_PU50: R302.2, SJ151.1
CS_M_PU51: R308.2, SJ154.1
CS_M_PU52: R314.2, SJ157.1
CS_M_PU53: R320.2, SJ160.1
CS_M_PU54: R326.2, SJ163.1
CS_M_PU55: R332.2, SJ166.1
CS_M_PU56: R338.2, SJ169.1
CS_M_PU57: R344.2, SJ172.1
CS_M_PU58: R350.2, SJ175.1
CS_M_PU59: R356.2, SJ178.1
DEN_A/G: JP2.9, U1.13
DEN_A/G1: JP4.9, U2.13
DEN_A/G2: JP6.9, U3.13
DEN_A/G3: JP8.9, U4.13
DEN_A/G4: JP10.9, U5.13
DEN_A/G5: JP12.9, U6.13
DEN_A/G6: JP14.9, U7.13
DEN_A/G7: JP16.9, U8.13
DEN_A/G8: JP18.9, U9.13
DEN_A/G9: JP20.9, U10.13
DEN_A/G10: JP22.9, U11.13
DEN_A/G11: JP24.9, U12.13
DEN_A/G12: JP26.9, U13.13
DEN_A/G13: JP28.9, U14.13
DEN_A/G14: JP30.9, U15.13
DEN_A/G15: JP32.9, U16.13
DEN_A/G16: JP34.9, U17.13
DEN_A/G17: JP36.9, U18.13
DEN_A/G18: JP38.9, U19.13
DEN_A/G19: JP40.9, U20.13
DEN_A/G20: JP42.9, U21.13
DEN_A/G21: JP44.9, U22.13
DEN_A/G22: JP46.9, U23.13
DEN_A/G23: JP48.9, U24.13
DEN_A/G24: JP50.9, U25.13
DEN_A/G25: JP52.9, U26.13
DEN_A/G26: JP54.9, U27.13
DEN_A/G27: JP56.9, U28.13
DEN_A/G28: JP58.9, U29.13
DEN_A/G29: JP60.9, U30.13
DEN_A/G30: JP62.9, U31.13
DEN_A/G31: JP64.9, U32.13
DEN_A/G32: JP66.9, U33.13
DEN_A/G33: JP68.9, U34.13
DEN_A/G34: JP70.9, U35.13
DEN_A/G35: JP72.9, U36.13
DEN_A/G36: JP74.9, U37.13
DEN_A/G37: JP76.9, U38.13
DEN_A/G38: JP78.9, U39.13
DEN_A/G39: JP80.9, U40.13
DEN_A/G40: JP82.9, U41.13
DEN_A/G41: JP84.9, U42.13
DEN_A/G42: JP86.9, U43.13
DEN_A/G43: JP88.9, U44.13
DEN_A/G44: JP90.9, U45.13
DEN_A/G45: JP92.9, U46.13
DEN_A/G46: JP94.9, U47.13
DEN_A/G47: JP96.9, U48.13
DEN_A/G48: JP98.9, U49.13
DEN_A/G49: JP100.9, U50.13
DEN_A/G50: JP102.9, U51.13
DEN_A/G51: JP104.9, U52.13
DEN_A/G52: JP106.9, U53.13
DEN_A/G53: JP108.9, U54.13
DEN_A/G54: JP110.9, U55.13
DEN_A/G55: JP112.9, U56.13
DEN_A/G56: JP114.9, U57.13
DEN_A/G57: JP116.9, U58.13
DEN_A/G58: JP118.9, U59.13
DEN_A/G59: JP120.9, U60.13
DRDY_M: JP2.5, U1.9
DRDY_M1: JP4.5, U2.9
DRDY_M2: JP6.5, U3.9
DRDY_M3: JP8.5, U4.9
DRDY_M4: JP10.5, U5.9
DRDY_M5: JP12.5, U6.9
DRDY_M6: JP14.5, U7.9
DRDY_M7: JP16.5, U8.9
DRDY_M8: JP18.5, U9.9
DRDY_M9: JP20.5, U10.9
DRDY_M10: JP22.5, U11.9
DRDY_M11: JP24.5, U12.9
DRDY_M12: JP26.5, U13.9
DRDY_M13: JP28.5, U14.9
DRDY_M14: JP30.5, U15.9
DRDY_M15: JP32.5, U16.9
DRDY_M16: JP34.5, U17.9
DRDY_M17: JP36.5, U18.9
DRDY_M18: JP38.5, U19.9
DRDY_M19: JP40.5, U20.9
DRDY_M20: JP42.5, U21.9
DRDY_M21: JP44.5, U22.9
DRDY_M22: JP46.5, U23.9
DRDY_M23: JP48.5, U24.9
DRDY_M24: JP50.5, U25.9
DRDY_M25: JP52.5, U26.9
DRDY_M26: JP54.5, U27.9
DRDY_M27: JP56.5, U28.9
DRDY_M28: JP58.5, U29.9
DRDY_M29: JP60.5, U30.9
DRDY_M30: JP62.5, U31.9
DRDY_M31: JP64.5, U32.9
DRDY_M32: JP66.5, U33.9
DRDY_M33: JP68.5, U34.9
DRDY_M34: JP70.5, U35.9
DRDY_M35: JP72.5, U36.9
DRDY_M36: JP74.5, U37.9
DRDY_M37: JP76.5, U38.9
DRDY_M38: JP78.5, U39.9
DRDY_M39: JP80.5, U40.9
DRDY_M40: JP82.5, U41.9
DRDY_M41: JP84.5, U42.9
DRDY_M42: JP86.5, U43.9
DRDY_M43: JP88.5, U44.9
DRDY_M44: JP90.5, U45.9
DRDY_M45: JP92.5, U46.9
DRDY_M46: JP94.5, U47.9
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

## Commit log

2015-02-04 Initial commit of hardware.
    [SparkFun-LSM9DS1-Breakout.brd, SparkFun-LSM9DS1-Breakout.sch]
2015-02-09 Cleaning up schematic.
    [SparkFun-LSM9DS1-Breakout.brd, SparkFun-LSM9DS1-Breakout.sch]
2015-02-09 Adding board mesurements, fixing some traces, labelling VCC range.
    [SparkFun-LSM9DS1-Breakout.brd, SparkFun-LSM9DS1-Breakout.sch]
2015-03-02 Re-arranging some silk. Updating board to v10.
    [SparkFun-LSM9DS1-Breakout.brd, SparkFun-LSM9DS1-Breakout.sch]
2015-03-02 Moving silk, adding GND vias, adding axis to bottom silk. Updating version to v10.
    [SparkFun-LSM9DS1-Breakout.brd]
2015-03-06 created panel v10
    [SparkFun-LSM9DS1-Breakout-Panel-v10.brd]
2015-08-13 Renaming directories.
    [SparkFun-LSM9DS1-Breakout-Panel-v10.brd, SparkFun-LSM9DS1-Breakout.brd, SparkFun-LSM9DS1-Breakout.sch]
2015-08-13 Squashed 'Libraries/Arduino/' content from commit 05cbe7b
    git-subtree-dir: Libraries/Arduino
    git-subtree-split: 05cbe7b8abbc9820736a54fdd6d2550e56e6d7b8
2018-08-20 Correct Temperature Calculation
    Updated how temperature is calculated according to the datasheet.
2018-08-24 Temperature Read Error
    Corrected method for reading temperature.
2018-08-27 Sync With LSM9DS1 Arduino Library
    Updated the following to bring it inline with Arduino Library:
    -Added return statements that prevent compilation in certain IDEs.
    -Updated how temperature is calculated.
2023-11-01 Fixes some minor discrepancies in return values, removes unused values or uninitialized arrays, rolls version, re-zips Arduino source files

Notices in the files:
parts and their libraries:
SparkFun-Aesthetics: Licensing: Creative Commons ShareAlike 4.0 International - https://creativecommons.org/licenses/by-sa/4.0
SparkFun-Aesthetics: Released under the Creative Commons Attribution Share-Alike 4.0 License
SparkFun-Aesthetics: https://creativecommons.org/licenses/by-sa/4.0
